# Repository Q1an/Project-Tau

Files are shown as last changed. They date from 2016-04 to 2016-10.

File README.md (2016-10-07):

#Project Tau
> Distributed Machine Learning For Reconfigurable  Modular Robots

##Concept
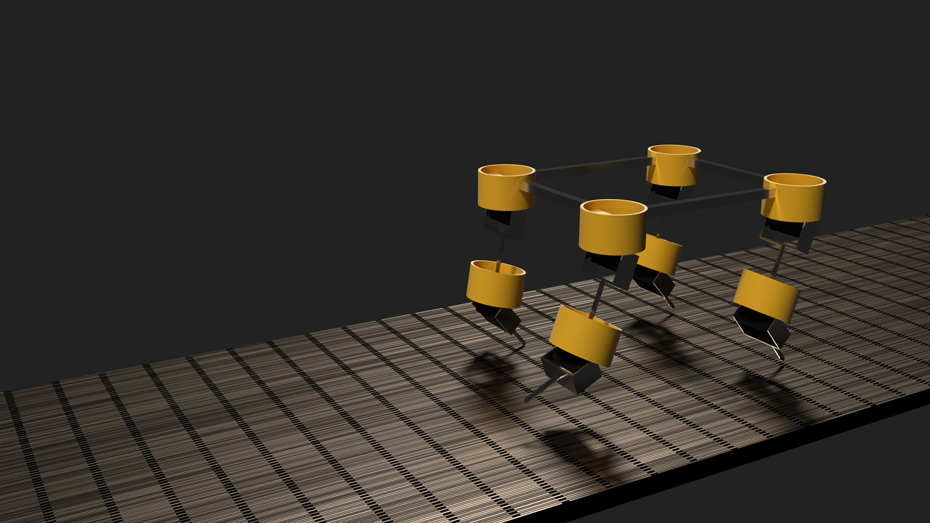
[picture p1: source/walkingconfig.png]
Walking Robot

Walking robot configuration.

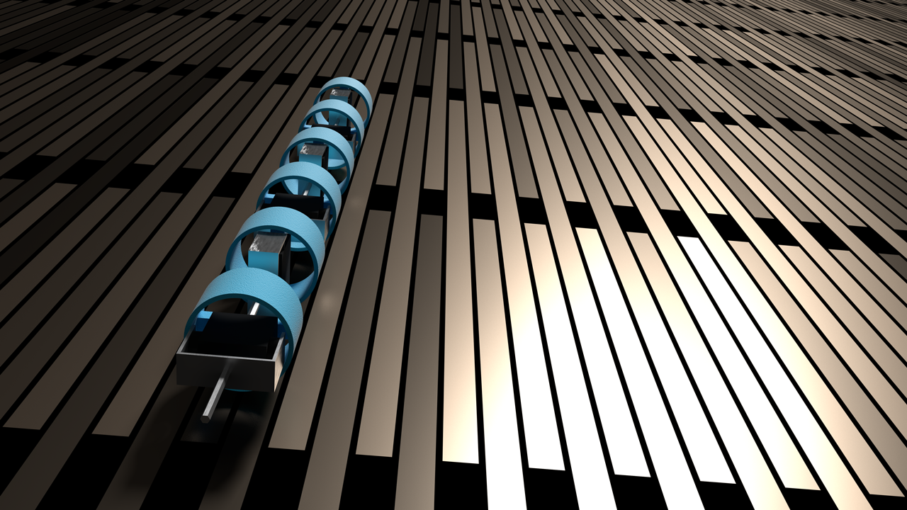
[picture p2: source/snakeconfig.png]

Snake robot configuration.
##Project Overview
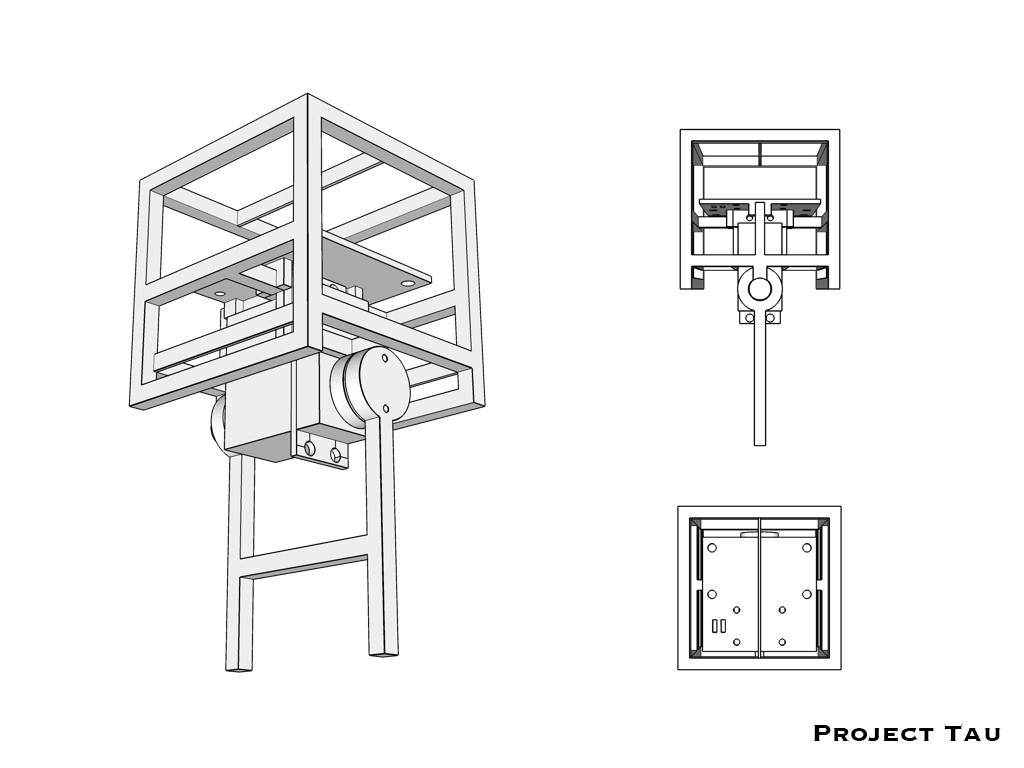
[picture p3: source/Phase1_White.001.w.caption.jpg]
blueprint

This project is intended to build a group of simple robots that learns how to move cooperatively based on the way they are assembled. While each robot has only one leg which moves forward and backward, the system can support much more complicated moving strategies, such as walking, running and rotating.  

##Hardware Design
The mechanical structure of the robot consists of a 3D-printed, 70mm body frame and a servomotor driven leg. The main processor of the robot is ESP8266, a low-cost, Wi-Fi embedded board, connected with a BNO055 IMU. 

##Project Objectives
For the first two phases of the project, all robots will be connected to a host through a single, shared network. The IMU data sent from each robot will be handled by a server program, and then used to calculate an optimal moving strategy. Starting from the second phase, the system will attempt to move based on strategies learnt from real-time feedback and past experience. At the third phase, the host no longer oversees the whole process, rather, it will be split into a number of virtual simulators each corresponding to a robot. Every simulator only knows about the sensor data sent from its corresponding robot, and information exchanged with its nearby simulators. In the final phase of this project, the optimized, lightweight simulator will migrate to ESP8266 so that the distributive system can run without the host. 

####Phase 0 [Completed - Apr 05, 2016]

- settle down project topic;
- decide on project visions;

####Phase 1  [Completed - Apr 28, 2016]
groupwalking    
**iteration 1**   

- design the mechanical structure of the robot; assemble prototypes;  
- setup local web server to receive IMU data sent from each robot;   
- send moving instructions through Wi-Fi to each robot based on a naive, deterministic algorithm;
- assemble a four-robot system; the system is able to move steadily;   

**iteration 2**

- use new stable servo
- standardize model:
  - easy to assemble
  - legs are of the same legnth
  - calibrate servo
- modify robot design to accommodate requirements of power supply; use flexible cable;
- check MCU code to solve occasional delays
- based on IMU to know directions
- work on the server programin preparation for phase 2; 

####Phase 2  [Ongoing]

- build a long-lasting and safe playground;
- optimaize the developed moving strategy based on ML algorithm;
- regulate the data received, establish the learnign model;
- build a database to store relevant info.
- try more advanced ML algorithmsto tune the robots;

####Phase 3

- realize simulators on the host;
- without prior knowledge of how it is assembled, the system is able to develop satisfying optimal stategies through learning; 
- support more interesting ways of assembling these robots;
- the system can move on different terrains;

####Phase 4

- optimize the algorithm of simulator; simulator migrates to ESP8266;
- realize communication between nearby robots;
- the system can move on various situations regardless of how it is assembled;

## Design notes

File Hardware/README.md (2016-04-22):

####log:
phase1 5 -> 6: add two tapped holes to the leg and modify the front support of the servo
phase1 6 -> 7: design support
phase1 7 -> 8: modify body to reduce support for 3d printer

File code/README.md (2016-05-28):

## Deliverable
### ESP8266
servo: A simple program to control servo via servo.h  
BNO055: A program that read fusion and raw data from IMU  
Network: A simple http client that can post and get data  
Dataprocess: An integrated program that can send the data from IMU to the Host via HTTP POST and get data from the host to control servo  
### HOST
simpleserver: A simple server program that can printout the HTTP GET and POST requests  
phase1: The program for phase 1, include a simple visualization using OPENGL    
phase2: Programs for phase 2, with framework as shown in the picture below:
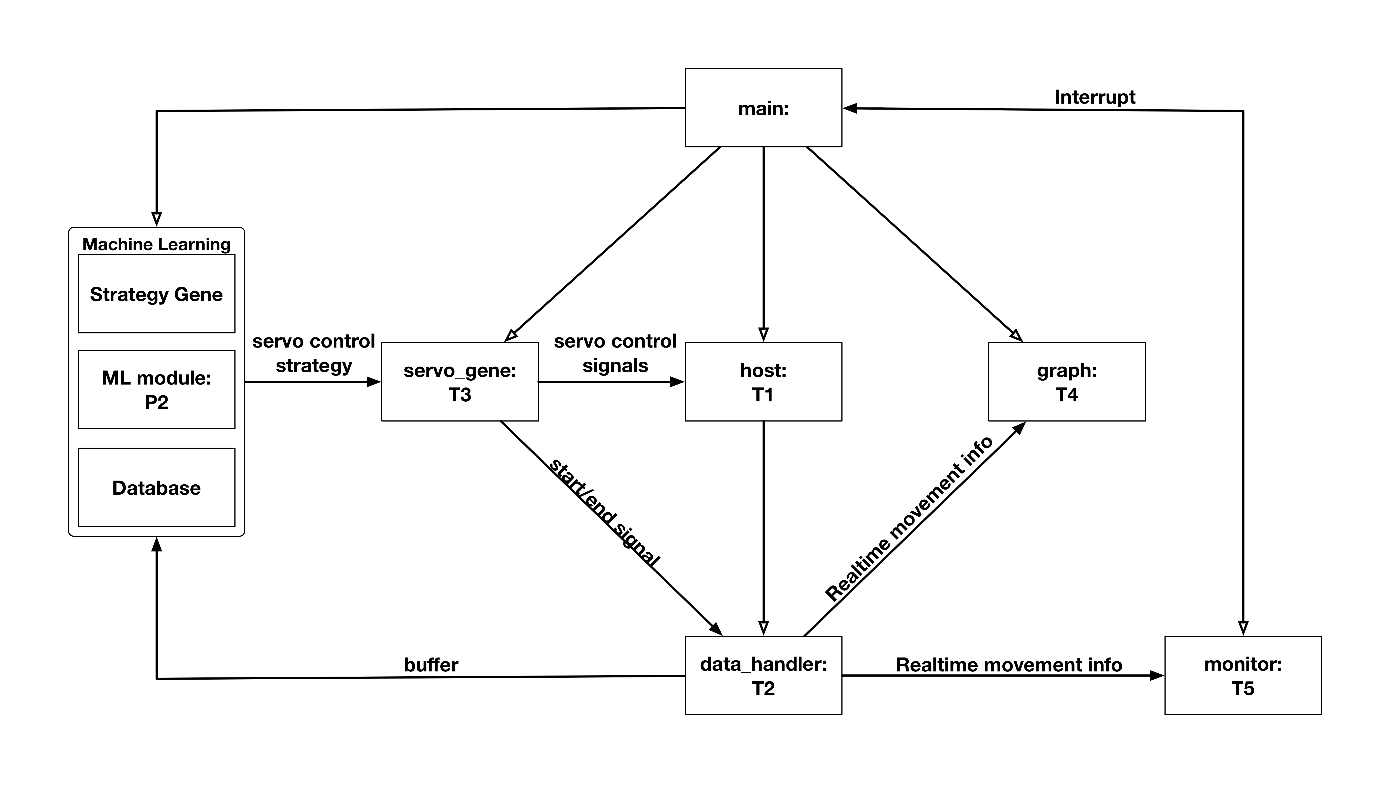
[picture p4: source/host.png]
framework


## Communication Format
### ESP8266 → host
30 bytes:  
6	GYROSCOPE(X,Y,Z)     - rad/s     - 1rps = 900 LSB  
6	LINEARACCEL(X,Y,Z)   - m/s^2 	 - 1m/s^2 = 100 LSB  
6	EULER(X,Y,Z)         - degrees   - 1 degree = 16 LSB  
8	QUAT(W,X,Y,Z)			 - quat unit  - 1 Quaternion = 2^14 LSB     
4	TIME    
where X,Y,Z are 16bits unsigned int  
### host → ESP8266
servo control signals

#TODO
+ Too many threads in one cpu core -> high temperature -> introduce multi processes

+ need to wait for the file io operation , otherwise cannot record the complete data

+ where to check the overturn, now it is in the graph :)

+ need to create a robot object and use manager() to share among processes

+ Graph be a seperate thread?

+ the format of the data stored

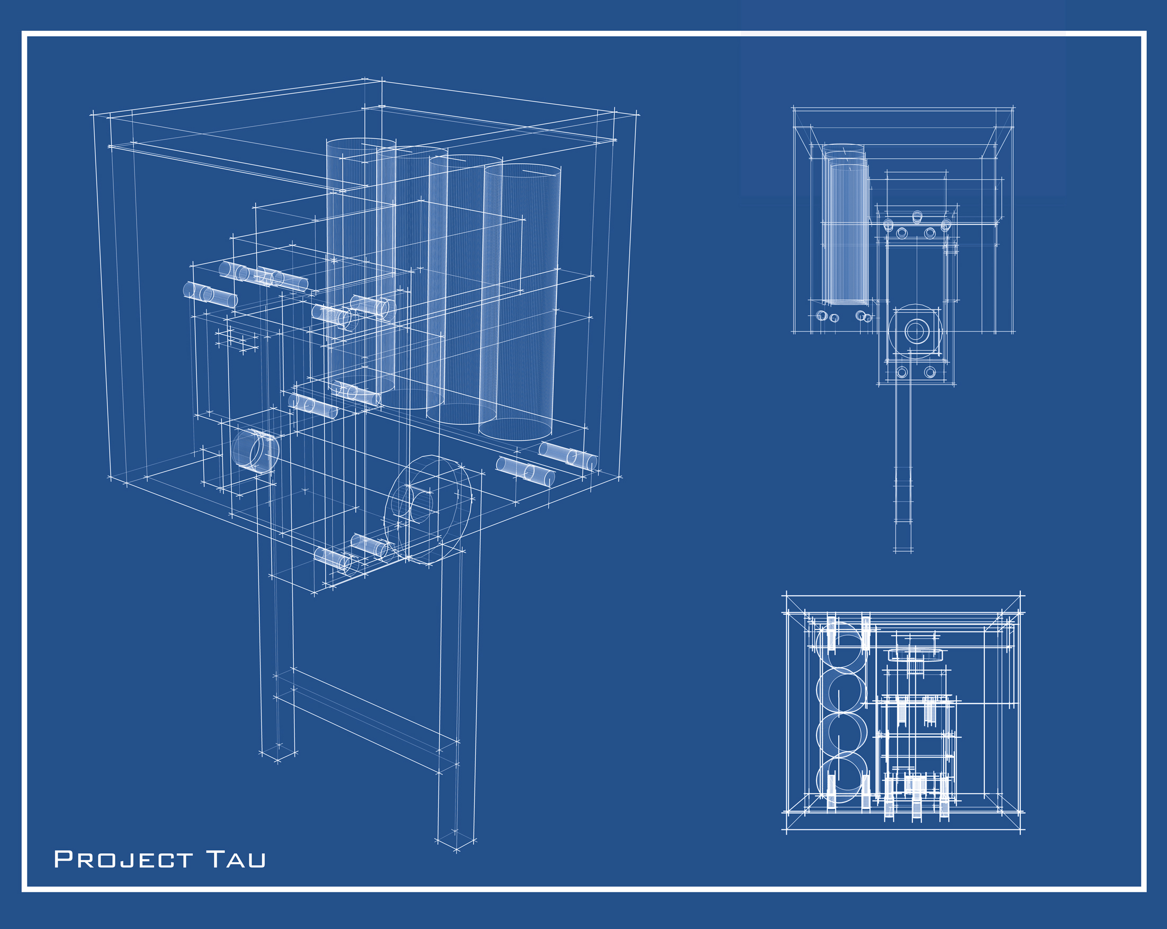
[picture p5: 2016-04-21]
source/bp_web.jpg

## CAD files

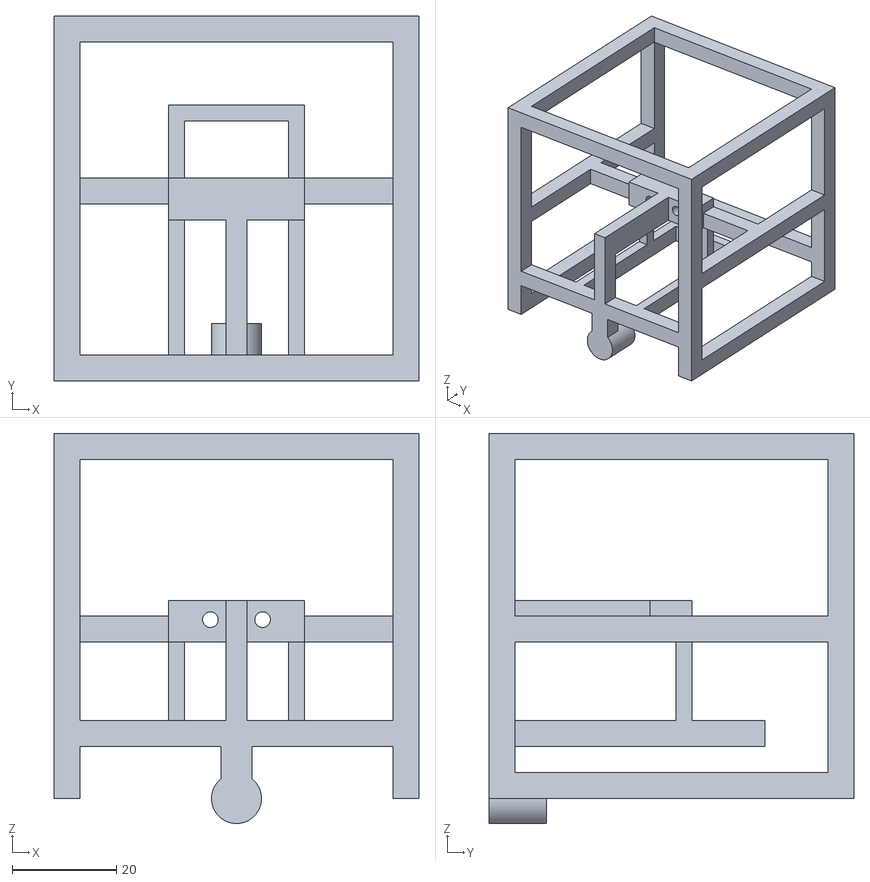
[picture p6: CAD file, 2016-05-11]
Hardware/output/body.stl
70.0 x 70.0 x 74.8

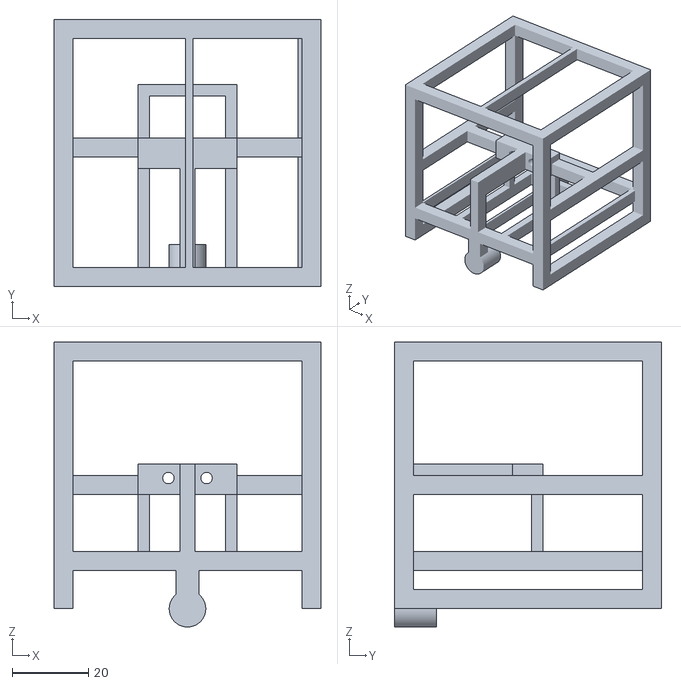
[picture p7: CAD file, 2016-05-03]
Hardware/output/body_with_support.stl
70.0 x 70.0 x 74.8

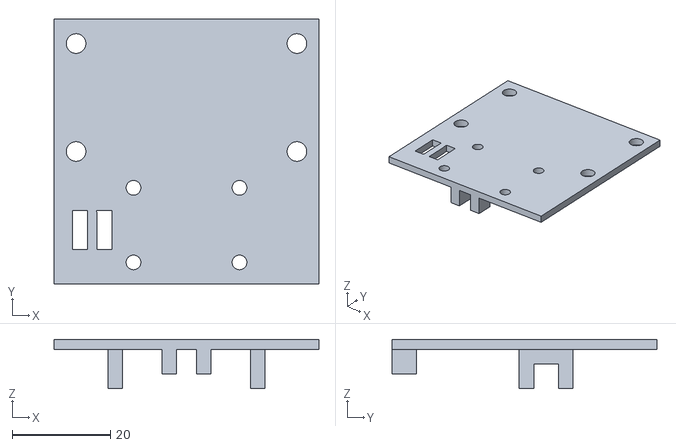
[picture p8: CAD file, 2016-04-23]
Hardware/output/support.stl
54.0 x 54.0 x 10.0

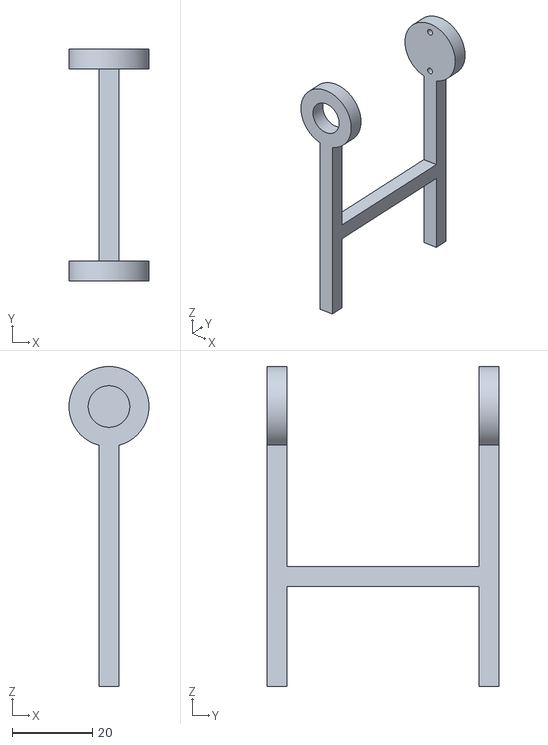
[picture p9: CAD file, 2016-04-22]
Hardware/output/leg.stl
20.0 x 58.0 x 80.0

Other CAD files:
Hardware/phase1 final 1.skp
Hardware/phase1 final 2.skp
Hardware/phase1 final 3 3mm.skp
Hardware/phase1 final 3.skp
Hardware/phase1 final 4.skp
Hardware/phase1 final 5.skp
Hardware/phase1 final 6.skp
Hardware/phase1 final 7.skp
Hardware/phase1 final 8 presen5.skp
Hardware/phase1 final 8.1.skp
Hardware/phase1 final 8.skp
Hardware/phase1(1.0).skp

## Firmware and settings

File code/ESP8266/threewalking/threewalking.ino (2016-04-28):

#include <Wire.h>
#include <Arduino.h>
#include <ESP8266WiFi.h>
#include <ESP8266WiFiMulti.h>
#include <ESP8266HTTPClient.h>
#include <Servo.h>
#include "Adafruit_BNO055.h"
#include "imumaths.h"

#define USE_SERIAL Serial
#define BNO055_SAMPLERATE_DELAY_MS (100)

Adafruit_BNO055 bno = Adafruit_BNO055();
ESP8266WiFiMulti WiFiMulti;

Servo s1;
Servo s2;
Servo s3;
Servo s4;
int Servo_PIN1 = 14; //NodeMCU D5
int Servo_PIN2 = 12; //NodeMCU D6
int Servo_PIN3 = 13; //NodeMCU D7
int Servo_PIN4 = 15; //NodeMCU D8

void displaySensorStatus(void)
{
  uint8_t system_status, self_test_results, system_error;
  system_status = self_test_results = system_error = 0;
  bno.getSystemStatus(&system_status, &self_test_results, &system_error);

  /* Display the results in the Serial Monitor */
  Serial.println("");
  Serial.print("System Status: 0x");
  Serial.println(system_status, HEX);
  Serial.print("Self Test:     0x");
  Serial.println(self_test_results, HEX);
  Serial.print("System Error:  0x");
  Serial.println(system_error, HEX);
  Serial.println("");
  delay(500);
}

void setup() {

    USE_SERIAL.begin(115200);
    // USE_SERIAL.setDebugOutput(true);

    USE_SERIAL.print("\n\n\n");

    for(uint8_t t = 5; t > 0; t--) {
        USE_SERIAL.printf("[SETUP] WAIT %d...\n", t);
        USE_SERIAL.flush();
        delay(1000);
    }

    WiFiMulti.addAP("Tau", "314159265358");

    Serial.println("IMU Initialization\n");
    /* Initialise the sensor */
    if(!bno.begin())
    {
      /* There was a problem detecting the BNO055 ... check your connections */
      Serial.print("Ooops, no BNO055 detected ... Check your wiring or I2C ADDR!");
      while(1);
    }
  
    delay(1000);
    bno.setExtCrystalUse(true);
    displaySensorStatus();
    s1.attach(Servo_PIN1);
    s2.attach(Servo_PIN2);
    s3.attach(Servo_PIN3);
    s4.attach(Servo_PIN4);
}

void loop() {
      // wait for WiFi connection
    if((WiFiMulti.run() == WL_CONNECTED)) {

        HTTPClient http;

        USE_SERIAL.print("[HTTP] begin...\n");

        // configure server and url
        http.begin("http://192.168.1.74:8000/");

        USE_SERIAL.print("[HTTP] POST...\n");
        
        // start connection and send HTTP header
        
        /*
         * get data from IMU and send
         *
         * Possible vector values can be:
         * - VECTOR_ACCELEROMETER - m/s^2
         * - VECTOR_MAGNETOMETER  - uT
         * - VECTOR_GYROSCOPE     - rad/s     - 1rps = 900 LSB
         * - VECTOR_EULER         - degrees   - 1 degree = 16 LSB
         * - VECTOR_LINEARACCEL   - m/s^2     - 1m/s^2 = 100 LSB
         * - VECTOR_GRAVITY       - m/s^2
         * 
         */
        
        uint8_t gyro[6]; memset (gyro, 0, 6);
        uint8_t linearacc[6]; memset (linearacc, 0, 6);
        uint8_t euler[6]; memset (euler, 0, 6);
    
        bno.getData(Adafruit_BNO055::VECTOR_GYROSCOPE, gyro);
        bno.getData(Adafruit_BNO055::VECTOR_LINEARACCEL, linearacc);
        bno.getData(Adafruit_BNO055::VECTOR_EULER, euler);
        
//        imu::Vector<3> eul = bno.getVector(Adafruit_BNO055::VECTOR_EULER);
//        
//        /* Display the floating point data */
//        Serial.println("Euler: ");
//        Serial.print("X: ");
//        Serial.print(eul.x());
//        Serial.print(" Y: ");
//        Serial.print(eul.y());
//        Serial.print(" Z: ");
//        Serial.print(eul.z());
//        Serial.println("\t");
//        
//        imu::Vector<3> lineacc = bno.getVector(Adafruit_BNO055::VECTOR_LINEARACCEL);
//        
//        Serial.println("Linear Acc: ");
//        Serial.print("X: ");
//        Serial.print(lineacc.x(), 4); 
//        Serial.print(" Y: ");
//        Serial.print(lineacc.y(), 4); 
//        Serial.print(" Z: ");
//        Serial.print(lineacc.z(), 4); 
//        Serial.println("\t");
//        
//        imu::Vector<3> anguvel = bno.getVector(Adafruit_BNO055::VECTOR_GYROSCOPE);
//      
//        /* Display the floating point data */
//        Serial.println("Angular velocity: ");
//        Serial.print("X: ");
//        Serial.print(anguvel.x());
//        Serial.print(" Y: ");
//        Serial.print(anguvel.y());
//        Serial.print(" Z: ");
//        Serial.print(anguvel.z());
//        Serial.println("\t");

        uint8_t datasent[18];
        memset(datasent, 0, 18);
        for (int i = 0; i < 6; i++)
          datasent[i] = gyro[i];
        for (int i = 0; i < 6; i++)
          datasent[i + 6] = linearacc[i];
        for (int i = 0; i < 6; i++)
          datasent[i + 12] = euler[i];
        
        int httpCode = http.POST(datasent, sizeof(datasent));
        
        if(httpCode > 0) {
            // HTTP header has been send and Server response header has been handled
            USE_SERIAL.printf("[HTTP] POST... code: %d\n", httpCode);

            // file found at server
            if(httpCode == HTTP_CODE_OK) {
                String payload = http.getString();
                int servo1 = payload.substring(0,3).toInt();
                int servo2 = payload.substring(3,6).toInt();
                int servo3 = payload.substring(6,9).toInt();
                int servo4 = payload.substring(9,12).toInt();
                int val1 = servo1-100;
                int val2 = servo2-100;  
                int val3 = servo3-100;  
                int val4 = servo4-100;       
                s1.write(val1);
                s2.write(val2);
                s3.write(val3);
                s4.write(val4);
                delay(50);
                USE_SERIAL.println(val1);
                USE_SERIAL.println(val2);
                USE_SERIAL.println(val3);
                USE_SERIAL.println(val4);
            }
        } else {
            USE_SERIAL.printf("[HTTP] POST... failed, error: %s\n", http.errorToString(httpCode).c_str());
        }

        http.end();
    }

    delay(50);
}

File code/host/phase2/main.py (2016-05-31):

import globalvar
import time, threading
import host
import graph
import datahandler
import servogene
import sys
import monitor
from multiprocessing import Process, Manager
import os
import numpy as numpy
import matplotlib.pyplot as plt

comb = []
for i in range(80,145,5):
	for j in range(80,145,5):
		comb.append([i,j])

best = [0 for i in range(169)]


def P2(fo,strategy_q,buffer_q):
	global best
	ns = [ 4, 10, 135,140, 90, 90]
	time.sleep(4)
	step = -5

	strategy_q.put(ns)
	while True:
		
		print "strategy generated ", ns
		while buffer_q.empty():
			time.sleep(0.01)
		while not buffer_q.empty():
			b = buffer_q.get()
		if b!=[]:
			if abs(b[8][-1])>0.001:
				max_index = numpy.argmax(b[2])
				min_index = numpy.argmin(b[2])

				if max_index < min_index:
					print "postive, continue",step
				else:
					step = - step
					print "negative, reverse", step
				ns[3] += step
				ns[2] += step
			else:
				step =- step
				ns[3] += step
				ns[2] += step

			# if abs(b[8][-1])>0.002:
			# 	if b[8][-1] < 0:
			# 		step = -step

			# # print "**************"
			# # print b[-1]
			# # if b[-1]>0:
			# # 	print "postive, continue", step
			# # else:
			# # 	print "negative, previous", step, "reverse"
			# # 	step = -step
			# 	ns[3] += step
			# 	ns[2] += step
			# else:
			# 	step =- step
			# 	ns[3] += step
			# 	ns[2] += step

			if ns[2] >155 or ns[2] < 75:
				ns[2],ns[3]=135,135 
			fo.write(str(b[2])+'\n')

		time.sleep(0.4)
		strategy_q.put(ns)


# def P2(fo,strategy_q,buffer_q):
# 	ns = [ 4, 7, 135,140, 90, 90,0.8,90,90,90,90]
# 	while True:
# 		strategy_q.put(ns)
# 		time.sleep(2)

# def P2(fo,strategy_q,buffer_q):
# 	ns = [ 4, 7, 135,140, 90, 90,0.8,135,140,90,90]
# 	time.sleep(2)
# 	strategy_q.put(ns)

# 	while True:
# 		for k in range(len(comb)):
# 			while buffer_q.empty():
# 				time.sleep(0.01)
# 			while not buffer_q.empty():
# 				b = buffer_q.get()
# 			if b!=[]:
# 				ns[2]=comb[k][0]
# 				ns[3]=comb[k][1]
# 				strategy_q.put(ns)
# 				best[(k+168)%169]=max(best[(k+168)%169],b[8][-1])
# 			time.sleep(1)
# 			print best

def P1(fo,strategy_q,buffer_q):
	# t4 = threading.Thread(target=graph.run, name='graph')
	# t4.daemon = True
	# t4.start()
	# time.sleep(5)

	# plt initilization
	#plt.figure()
	f, axarr = plt.subplots(3, sharex=True)
	li = [axarr[i].plot([],[],'r',[],[],'b',[],[],'g') for i in xrange(3)]
	li.append(axarr)
	plt.setp(li[2][0],label="X-axis")
	plt.setp(li[2][1],label="Y-axis")
	plt.setp(li[2][2],label="Z-axis")
	axarr[0].set_title("Acceleration")
	axarr[1].set_title("Velocity")
	axarr[2].set_title("Displacement")
	box = axarr[2].get_position()
	axarr[2].set_position([box.x0, box.y0 + box.height * 0.2, box.width, box.height * 0.8])
	axarr[2].legend(loc='upper center', bbox_to_anchor=(0.5, -0.2), fancybox=True,ncol=3)

	# li = plt.plot([],[],'r',[],[],'b')
	plt.ion()
	plt.show(block=False)
	t1 = threading.Thread(target=host.serv, name='server')
	t1.daemon = True
	t1.start()
	t2 = threading.Thread(target=datahandler.handler, name='datahandler',args=(buffer_q,plt,li,))
	t2.daemon = True
	t2.start()
	print "datahandler start"
	t3 = threading.Thread(target=servogene.servo_gene, name='servo_generation',args=(strategy_q,))
	t3.daemon = True
	t3.start()
	print "servo_generation start"
	t5 = threading.Thread(target=monitor.monitor, name='monitor')
	t5.daemon = True
	t5.start()
	print "monitor start"
	# t6 = threading.Thread(target=ml, name='ml',args=(fo,))
	# t6.daemon = True
	# t6.start()
	graph.run()
	sys.exit()

if __name__=='__main__':
	manager = Manager()
	strategy_q = manager.Queue()
	buffer_q = manager.Queue()

	fo = open('stand.txt', 'w+')

	p1 = Process(target=P1, args=(fo,strategy_q,buffer_q,))
	p1.start()
	p2 = Process(target=P2, args=(fo,strategy_q,buffer_q,))
	p2.start()
	p1.join()
	p2.terminate()
	fo.write(str(best))
	fo.close()

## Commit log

2016-04-10 phase 1 sketchup 1.0
    [phase1(1.0).skp]
2016-04-20 servo added
2016-04-20 IMU done
2016-04-21 fetch data from IMU and send to server
2016-04-21 upload 3d model and stl
    [body.stl, leg.stl, phase1 final 1.skp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]
2016-04-21 leg updated
    [leg.stl]
2016-04-22 remove ~.sjp
    [phase1 final 5~.skp]
2016-04-22 hardware update
    [body.stl, leg.stl, phase1 final 5.skp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]
2016-04-24 3d printing support solved
    [phase1 final 8.1.skp]
2016-05-11 x3g, 2walk
    [body.stl]
2016-05-13 twowalking: trying to fix delay
    [twowalking.ino]
2016-05-28 phase 2 monitor + servo_gene
2016-05-28 servo-gene test
2016-05-30 servogene strategy formate update
2016-05-30 servo_gene update
